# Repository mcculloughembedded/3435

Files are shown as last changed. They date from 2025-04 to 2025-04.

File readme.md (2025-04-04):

# The 3435
The *3435* is a 34 key split keyboard inspired by the [Clog V3](https://sammohr.dev/keyboards).
I have used it daily in a professional setting for more than a year.

Title Image

## Features
* 34 key split
* Low profile - only 18mm from top of keycap to desk (including feet)
* Kailh Choc V1 low profile switches
* MX standard key spacing
* Ortholinear
* Angled columns
* Vertical key staggering
* Pinky cluster
* Two key thumb cluster
* Wired USB-C to PC
* Integrated microcontroller (ATMega32u4)
* Fully enclosed case

# Table of Contents
* [Order PCBs](./instructions/order.md)
* [Program](./instructions/program.md)
* [Assemble](./instructions/build.md)
* [Bill of Materials](./instructions/bill-of-materials.md)

Secondary Image

# What's With the Name?
3435 is my favourite number.
It is the only known number where if one raises each digit to the power of itself, then adds the results, one gets back the original number.

That is <br/>
$$3^3 + 4^4 + 3^3 + 5^5 = 3435$$

See [Matt Parker's talk](https://www.youtube.com/watch?v=wt5cRQY8F30) for a more in depth discussion.

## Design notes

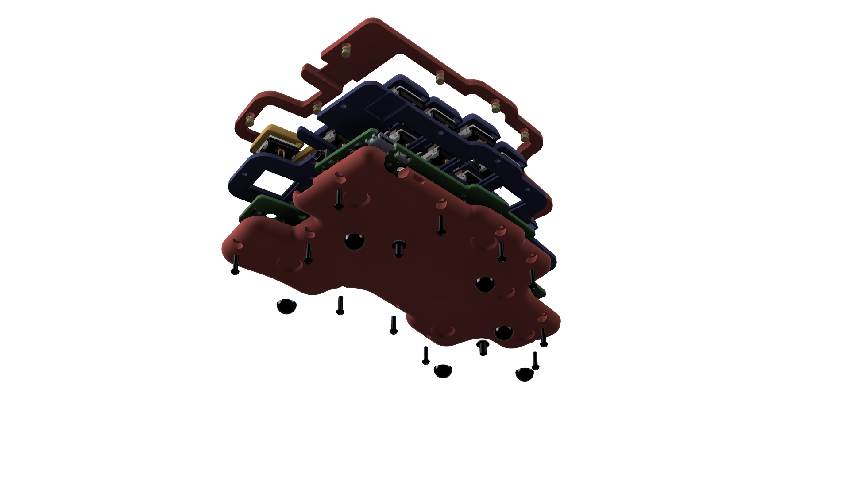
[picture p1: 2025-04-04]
collateral/renders/exploded-iso-bottom-left.png

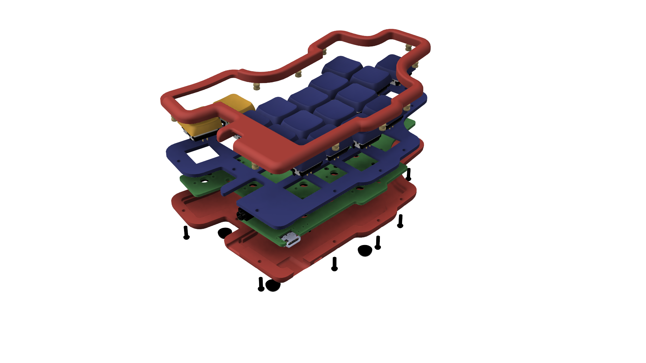
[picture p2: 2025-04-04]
collateral/renders/exploded-iso-right.png

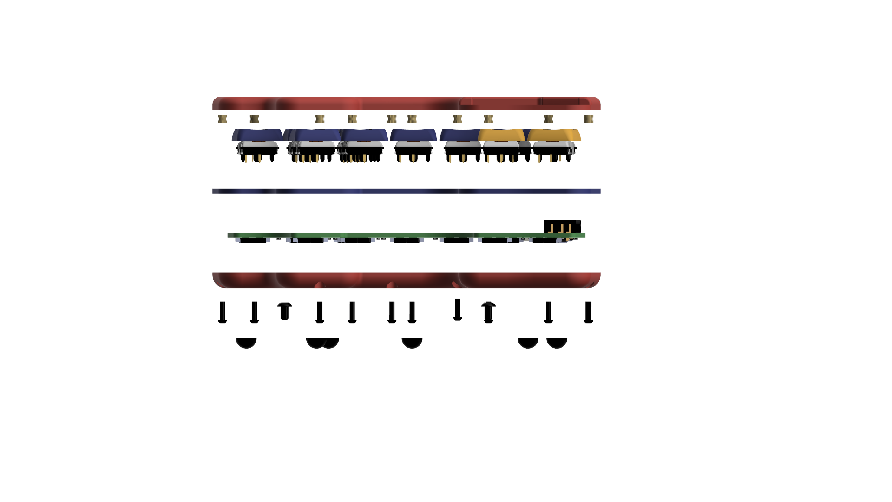
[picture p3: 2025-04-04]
collateral/renders/exploded-front.png

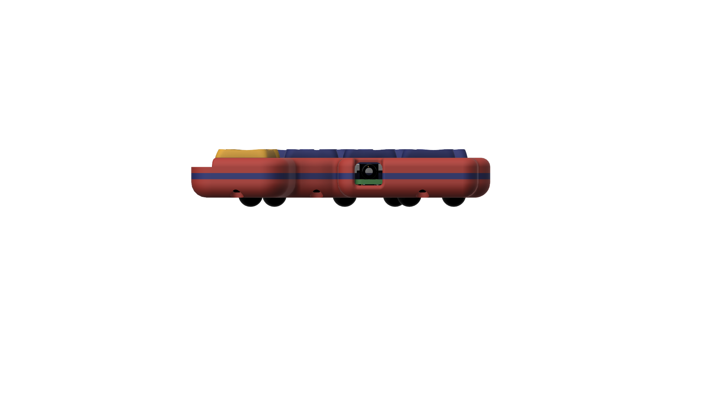
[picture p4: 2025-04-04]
collateral/renders/trrs-port.png

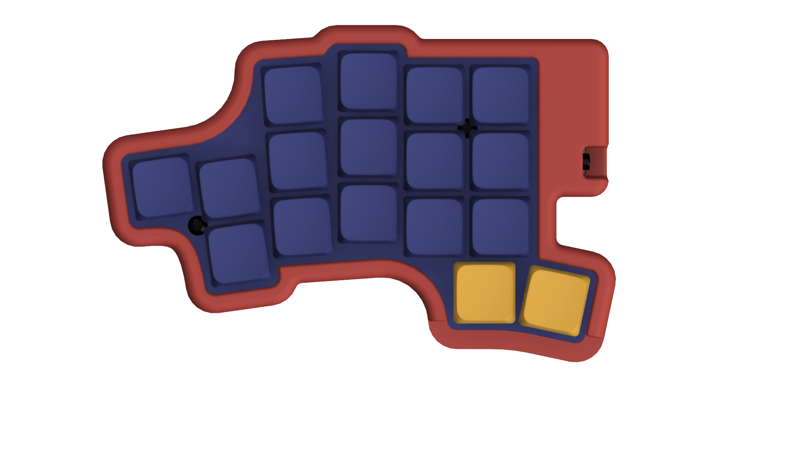
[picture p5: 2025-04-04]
collateral/renders/top.png

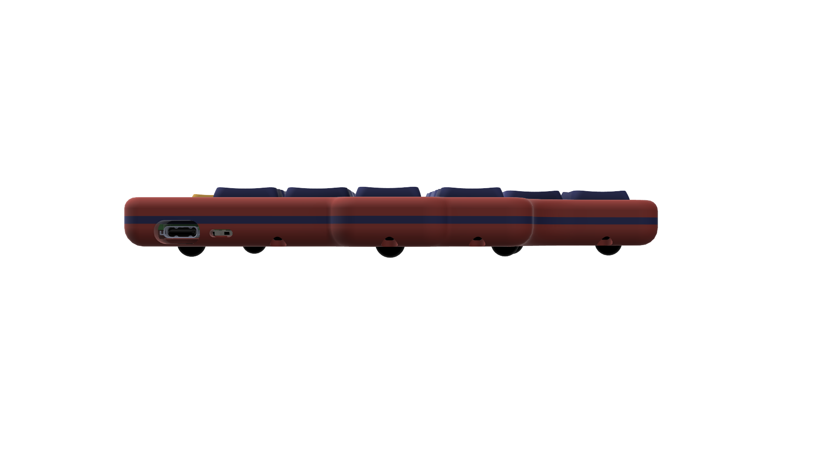
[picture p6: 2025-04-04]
collateral/renders/front.png

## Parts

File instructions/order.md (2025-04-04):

I use [JLCPCB](https://jlcpcb.com/) for all my PCBs.

# JLCPCB Datapacks
Each half of the keyboard is its own PCB order.
There are datapacks on the [Releases](https://github.com/mcculloughembedded/3435/releases) page with the required output files to order the PCBs from JLCPCB.
These datapacks include a bill of materials and a pick and place file excluding all top side components and the hot-swap sockets on the bottom side.

> :warning: **Disclaimer**<br>
The datapacks are unverified.
I did not have JLCPCB assemble everything for me.
Some components may be out of stock or no longer available.
In these cases you will have to select an alternative part from the JLC component library.
Make sure to double check everything before ordering!

If you would like to generate the output files yourself, there is a short discussion about doing so in the [Do It Yourself](#do-it-yourself) section.

# Order from JLCPCB
## Gerbers
If using a pre-generated datapack, simply upload `gerbers.zip` for each half of the keyboard.
The following options must be selected when uploading the gerber files.
Use your discretion for any other listed options.

| Option | Selection |
| --- | --- |
| Base Material | FR4 |
| Layers | 2 |
| PCB Thickness | 1.6mm |
| PCB Color | Any |
| Surface Finish | Lead Free HASL / ENIG[^1] |

## Assembly
This section is only relevant if JLCPCB will assemble the PCBs for you.

On the order page there is an option to have JLCPCB assemble the PCBs.
One thing to note here is that the USB-C connector is not on the same side as the rest of the components.
JLCPCB charges more to assemble both sides of the PCB.

The most economic way to do this is to have JLCPCB assemble the bottom side only.
Be warned though, soldering a USB-C connector is not a trivial task!

If using the datapacks, simply upload `bom.csv` and `pick-and-place.csv` when prompted and edit according to your needs.

JLCPCB has an online interface to visually check the placement of components.
Make sure of the orientation of the diodes, crystal oscillator and microcontroller.
I always edit the pick and place file locally and re-upload.
That way I am left with a correct pick and place file on my computer once all the corrections have been made.

Also make sure that JLCPCB stocks the parts in the bill of materials.
Again, they have an online interface to help with this.

# Do It Yourself

The requirements for a different PCB manufacturer will be similar but different to what is outlined here.

## PCB Output Files

At a minimum, PCB manufacturers require gerber and drill files to make the PCBs.

Consult the requirements of your chosen PCB manufacturer to know what they require.
For example, JLCPCB's website states that they require the following layers
* Top Copper
* Bottom Copper
* Top Solder Mask
* Bottom Solder Mask
* Top Silkscreen
* Bottom Silkscreen
* Board Outline

Each half of the keyboard is it's own [KiCad](https://www.kicad.org/) project.
Install KiCad and open each project using the *.kicad_pro* files in the `/pcbs/left` and `/pcbs/right` folders.

PCB manufactures often specify how to export gerber files correctly for different PCB software.
I used KiCad 7 and followed [these instructions](https://jlcpcb.com/help/article/how-to-generate-gerber-and-drill-files-in-kicad-7).

If you would like JLCPCB to assemble the PCBs for you, you must provide them with a bill of materials and a pick and place file.
JLCPCB has very specific requirements for these files.
KiCad does not export these files in the correct format for JLCPCB.
You have to edit them manually.
Consult the [JLCPCB documentation](https://jlcpcb.com/help/article/How-to-generate-the-BOM-and-Centroid-file-from-KiCAD) for more details.

[^1]: In short, ENIG is better, HASL is cheaper. I managed fine with HASL.

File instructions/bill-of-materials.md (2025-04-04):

> :warning: **Disclaimer**<br>
This BOM was written more than a year after the parts were ordered.
Some parts may no longer be available.
Part numbers may be incorrect.
I highly recommend that you double check everything before ordering.

# PCBs

| Part | (JLC) Part Number/Name | Quantity  | Notes/Footprint |
| --- | --- | --- | --- |
| Left Side PCB | 3435-left.kicad_pcb | 1 | |
| Right Side PCB | 3435-right.kicad_pcb | 1 | |
| 12pF Capacitor | | 4 | 0402 |
| 0.1uF Capacitor | | 10 | 0402 |
| 1uF Capacitor | | 2 | 0603 |
| 4.7uF Capacitor | | 2 | 0603 |
| Schottky Diode | B5819W SL | 2 | SOD-123 |
| Diode | 1N4148W | 34 | SOD-123 |
| Poly Fuse | SMD0805B050TF | 2 | 500mA/0805 |
| 22R Resistor | | 4 | 0402 |
| 5k1 Resistor | | 4 | 0402 |
| 10k Resistor | | 2 | 0402 |
| Slide Switch | PCM12SMTR | 2 | |
| Hot Swap Sockets | PG1350 | 34 | |
| 3.5mm TRRS Jack | PJ-320A | 2 | |
| USB-C Connector | USB4520-03-0-A | 2 | Mid Mount |
| Crystal Oscillator  | X322516MLB4SI | 2 | 16MHz/SMD3225-4P |
| Microcontroller | ATMega32U4 | 2 | VQFN-44 (7x7) |

# Mechanical

| Part | Part Number/Name  | Quantity  | Notes |
| --- | --- | --- | --- |
| Case Top Left | top.step | 1 | |
| Case Bottom Left | bottom.step | 1 | |
| Case Plate Left | plate.step | 1 | |
| Case Top Right | top.step | 1 | Mirrored |
| Case Bottom Right | bottom.step | 1 | Mirrored |
| Case Plate Right | plate.step | 1 | Mirrored |
| Threaded Inserts | M2x3x3.5mm | 22 | |
| Screws | M2x7 | 22 | |
| Rubber Ball Feet | 8mm diameter | 12 | Half dome adhesive bottom |

# Other

| Part | Part Number/Name  | Quantity  | Notes |
| --- | --- | --- | --- |
| Switches | Kailh Choc V1 | 34 | |
| Keycaps Standard | Choc V1 Keycap 1u | 28 | Concave |
| Keycaps Home Row | Choc V1 Keycap 1u | 2 | Bump on keycap  |
| Keycaps Thumb Cluster | Choc V1 Keycap 1u | 4 | Convex |
| USB-C to USB-A Cable | | 1 | |
| TRRS Cable | | 1 | |
| Right Angle TRRS Adapter | | 2 | Optional |

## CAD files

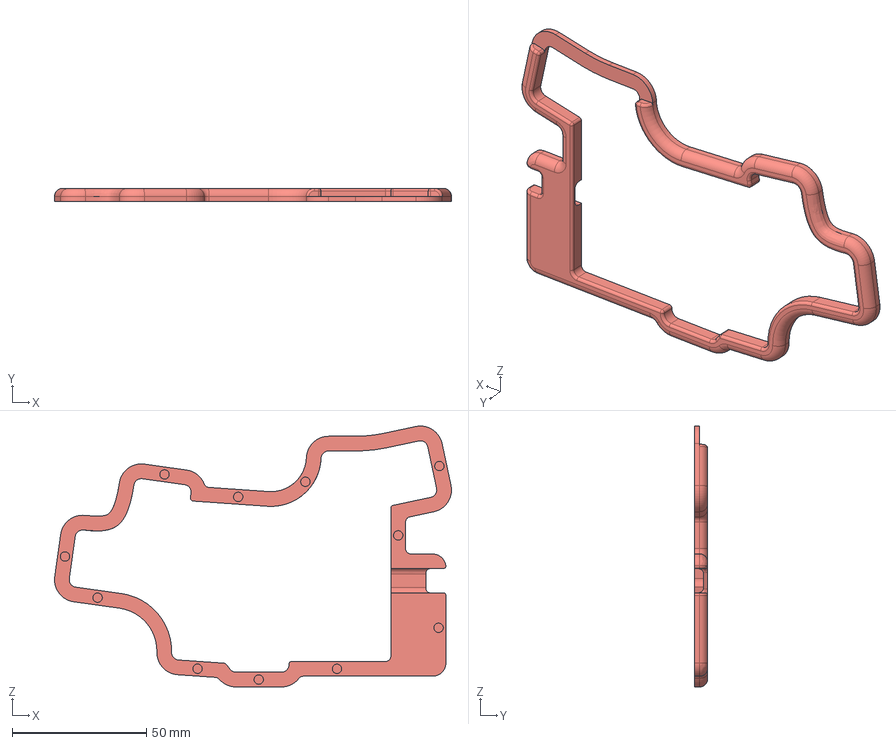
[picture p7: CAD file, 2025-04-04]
mechanical/top.step
148.1 x 5.00 x 97.3 mm

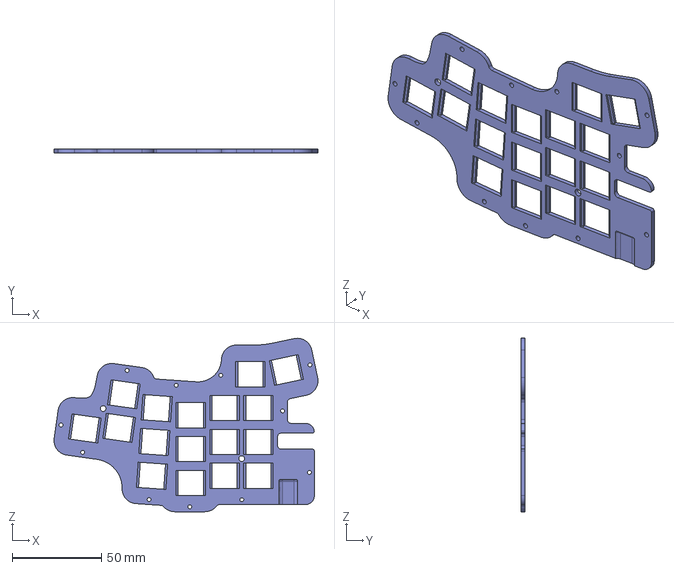
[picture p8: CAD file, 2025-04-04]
mechanical/plate.step
148.1 x 2.00 x 97.3 mm

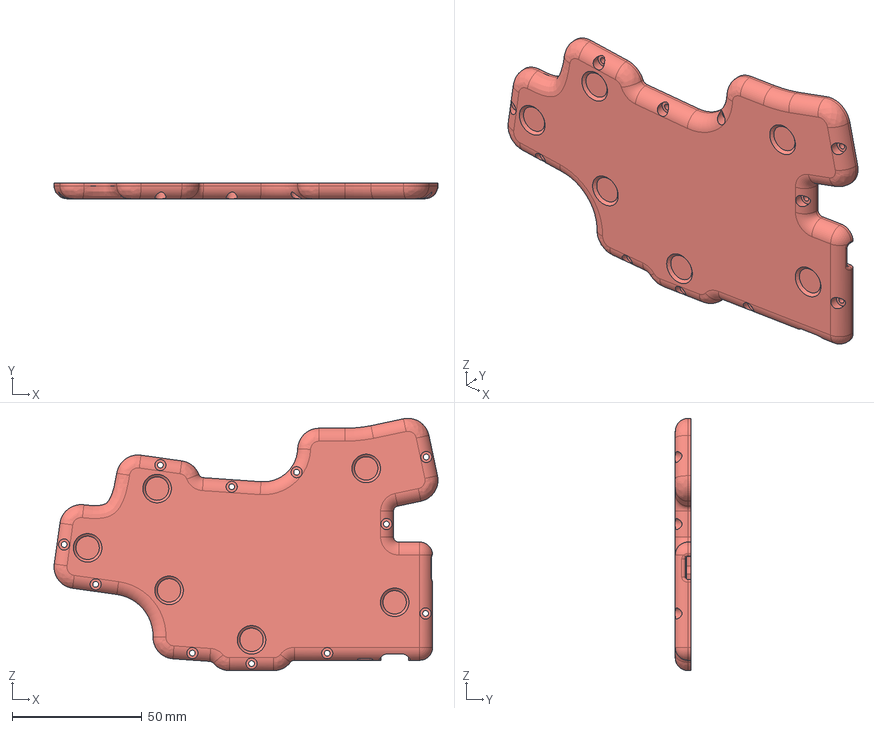
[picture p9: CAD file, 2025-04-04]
mechanical/bottom.step
148.1 x 6.00 x 97.3 mm

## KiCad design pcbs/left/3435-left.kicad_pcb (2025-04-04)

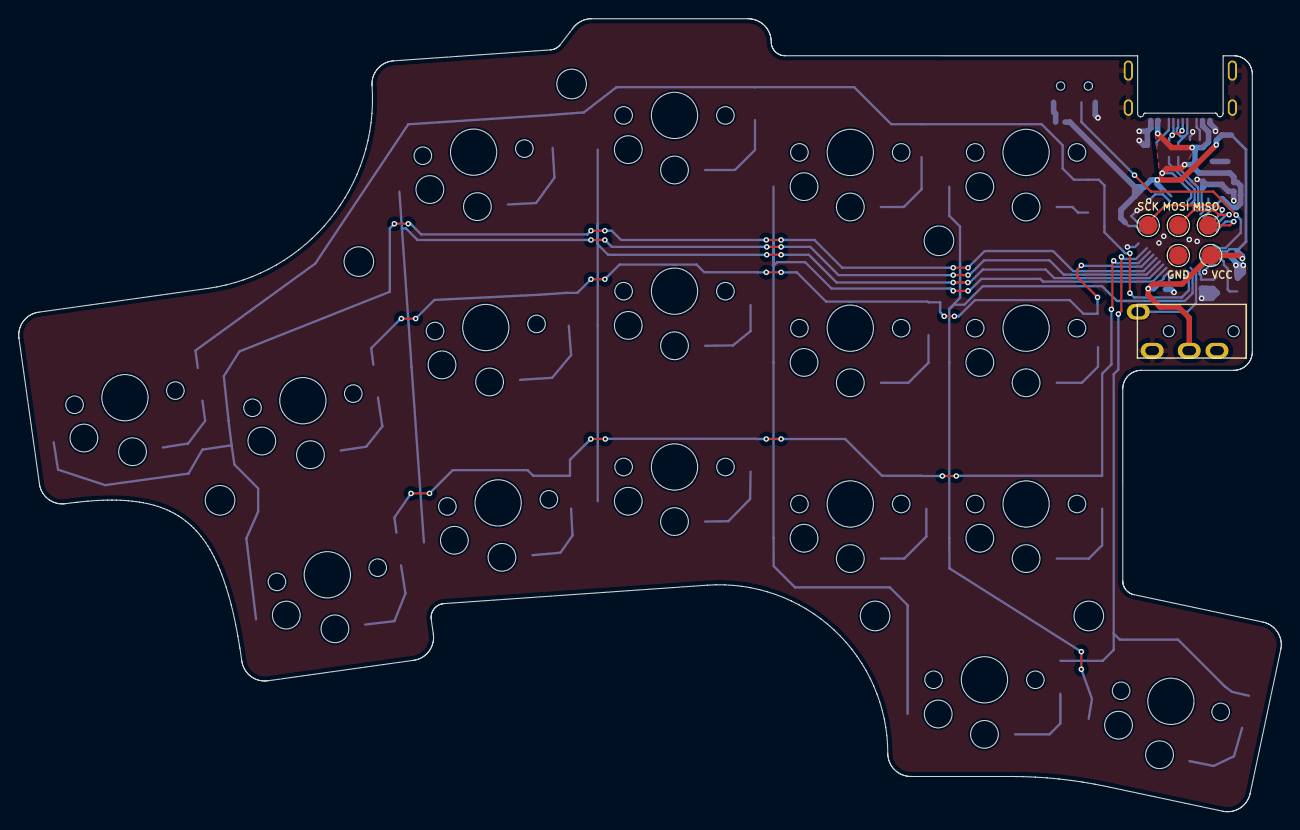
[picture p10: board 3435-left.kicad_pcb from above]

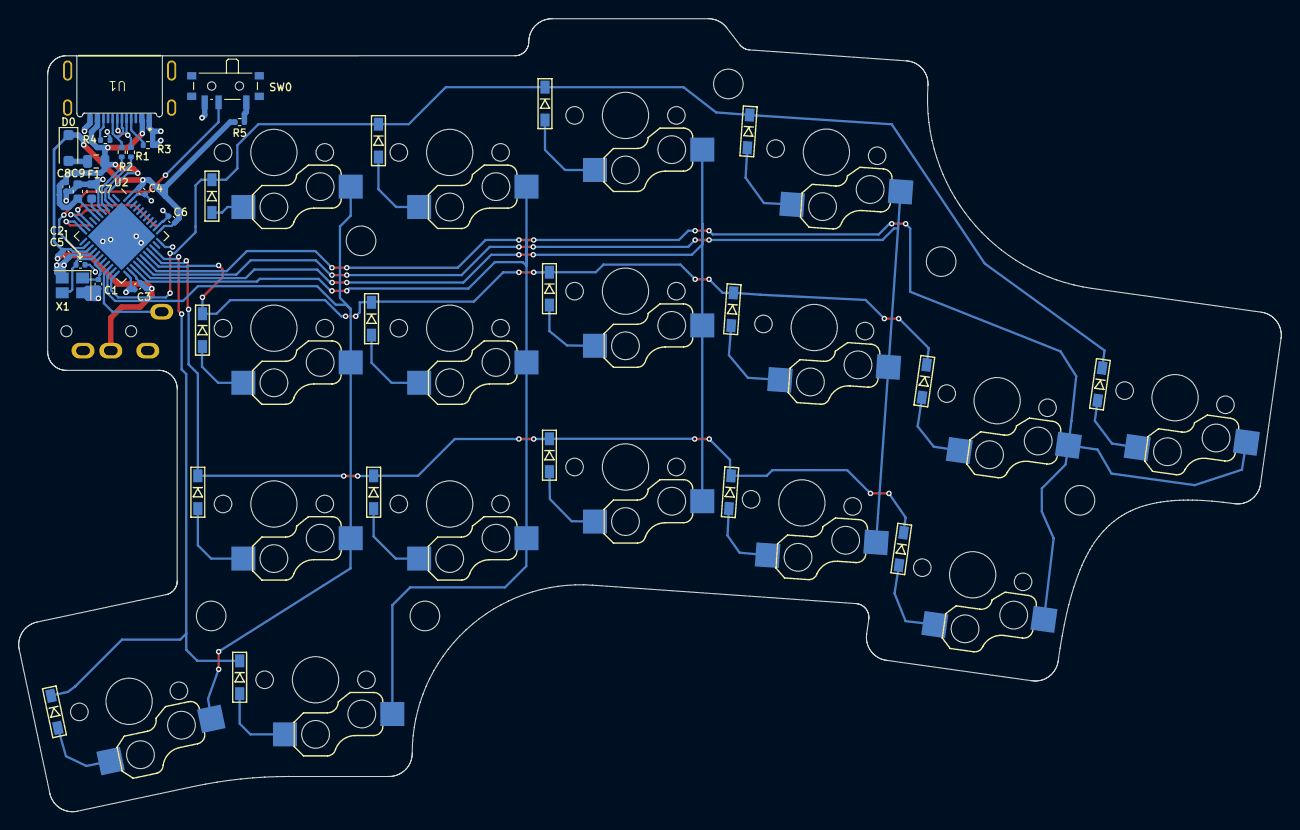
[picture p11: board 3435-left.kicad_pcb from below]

Board: 4 copper layers, 136.5 x 85.7 mm, 66 parts (37 on the bottom side), 45 nets.

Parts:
C1, C2: 12p; C_0402_1005Metric
C3, C4, C5, C6, C8: 0u1; C_0402_1005Metric
C7: 1u; C_0603_1608Metric
C9: 4u7; C_0603_1608Metric
D1, D2, D3, D4, D5, D6, D7, D8, D9, D10, D11, D12, D13, D14, D16, D17, D18: D; D3_SMD_v2
D15: D_Schottky; D_SOD-123F
F1: 500mA; Fuse_0805_2012Metric
H1, H2, H3, H4, H5, H6: MountingHole; MountingHole_3.2mm_M3
J1: MJ-4PP-9; MJ-4PP-9_1side
R1, R2: 22; R_0402_1005Metric
R3, R4: 5k1; R_0402_1005Metric
R5: 10k; R_0402_1005Metric
SW1, SW2, SW3, SW4, SW5, SW6, SW7, SW8, SW9, SW10, SW11, SW12, SW13, SW14, SW15, SW16, SW17: SW_PUSH; ChocV1_V2_Hotswap
SW18: SW_SPDT; SW_SPDT_PCM12
TP1, TP2, TP3, TP4, TP5: TestPoint; TestPoint_Pad_D2.0mm
U1: usb-mid-mount
U2: ATmega32U4-M; QFN-44-1EP_7x7mm_P0.5mm_EP5.2x5.2mm
X1: 16MHz; Crystal_SMD_SeikoEpson_FA238-4Pin_3.2x2.5mm

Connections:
/COL1: SW15.1, SW16.1, SW17.1, U2.28 (PB4)
/COL2: SW12.1, SW13.1, SW14.1, U2.27 (PD7)
/COL3: SW9.1, SW10.1, SW11.1, U2.26 (PD6)
/COL4: SW5.1, SW6.1, SW7.1, SW8.1, U2.25 (PD4)
/COL5: SW1.1, SW2.1, SW3.1, SW4.1, U2.21 (PD3)
/D+: R2.2, U2.4 (D+)
/D-: R1.1, U2.3 (D-)
/MISO: TP1.1, U2.11 (PB3)
/MOSI: TP4.1, U2.10 (PB2)
/RAW: D15.2 (A), F1.2
/RESET: SW18.2 (B), U2.13 (~RESET)
/ROW0: D1.1 (K), D5.1 (K), D9.1 (K), D12.1 (K), D16.1 (K), U2.22 (PD5)
/ROW1: D2.1 (K), D6.1 (K), D10.1 (K), D13.1 (K), D17.1 (K), U2.29 (PB5)
/ROW2: D3.1 (K), D7.1 (K), D11.1 (K), D14.1 (K), D18.1 (K), U2.30 (PB6)
/ROW3: D4.1 (K), D8.1 (K), U2.31 (PC6)
/SCK: TP2.1, U2.9 (PB1)
/serial: J1.A, U2.20 (PD2)
GND: C1.2, C2.2, C3.2, C4.2, C5.2, C6.2, C7.2, C8.2, C9.2, J1.D, R3.2, R4.1, SW18.3 (C), TP5.1, U1.A1_B12 (GND), U1.B1_A12 (GND), U1.S1 (SHIELD), U1.S2 (SHIELD), U1.S3 (SHIELD), U1.S4 (SHIELD), U2.5 (UGND), U2.15 (GND), U2.23 (GND), U2.33 (~HWB/PE2), U2.35 (GND), U2.43 (GND), U2.45 (GND), X1.2, X1.4
unnamed: D1.2 (A), SW1.2
unnamed: D2.2 (A), SW2.2
unnamed: D3.2 (A), SW3.2
unnamed: D4.2 (A), SW4.2
unnamed: D5.2 (A), SW5.2
unnamed: D6.2 (A), SW6.2
unnamed: D7.2 (A), SW7.2
unnamed: D8.2 (A), SW8.2
unnamed: D9.2 (A), SW9.2
unnamed: D10.2 (A), SW10.2
unnamed: D11.2 (A), SW11.2
unnamed: D12.2 (A), SW12.2
unnamed: D13.2 (A), SW13.2
unnamed: D14.2 (A), SW14.2
unnamed: D16.2 (A), SW15.2
unnamed: D17.2 (A), SW16.2
unnamed: D18.2 (A), SW17.2
unnamed: R1.2, U1.A7 (D-), U1.B7 (D-)
unnamed: R2.1, U1.A6 (D+), U1.B6 (D+)
unnamed: R5.1, SW18.1 (A)
unnamed: R3.1, U1.A5 (CC)
unnamed: R4.2, U1.B5 (VCONN)
unnamed: C7.1, U2.6 (UCAP)
unnamed: C1.1, U2.17 (XTAL1), X1.1
unnamed: C2.1, U2.16 (XTAL2), X1.3
VBUS: C8.1, C9.1, F1.1, U1.A4_B9 (VBUS), U1.B4_A9 (VBUS), U2.2 (UVCC), U2.7 (VBUS)
VCC: C3.1, C4.1, C5.1, C6.1, D15.1 (K), J1.C, R5.2, TP3.1, U2.14 (VCC), U2.24 (AVCC), U2.34 (VCC), U2.44 (AVCC)

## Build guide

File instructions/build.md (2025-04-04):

# PCB Assembly

Solder all components onto both the left and right hand side PCBs.
The microcontroller and USB-C connector are difficult to solder with a soldering iron.
The crystal oscillator must be soldered with a hot air station or oven.
The rest of the components can be soldered with a soldering iron, although there are a few 0402 components which can be a challenge.

Make sure to solder the diodes, crystal oscillator and microcontroller in the correct orientation!

PCB manufacturing outlets often provide an assembly service for an extra fee.
See [here](./order.md#Assembly).

# Mechanical Assembly

Before assembling the keyboard, make sure the [correct bootloader](./program.md#Bootloader) has been loaded!

The case is designed to be 3D printed on an FDM printer without supports.
I printed mine on my stock Creality Ender 3 V2.

1. 3D print `top.step`, `bottom.step` and `plate.step` from the `/mechanical` folder.
2. Push fit the threaded inserts into the holes on the bottom of *top.step*.
   This is best done by heating up the threaded inserts with a soldering iron before pushing them into position.
3. Clip the switches into their places on the top side of *plate.step*.
   There is only one way in which they will clip into place.
   The bottom side of *plate.step* has ridges onto which the switches clip.
4. With the PCB on the bottom side of *plate.step*, push the switches into their hot-swap sockets.
5. Sandwich *plate.step* in between *bottom.step* and *top.step*.
6. Screw in the screws from the bottom of the keyboard into the threaded inserts.
7. Stick on a rubber foot in each of the circular dents on the bottom of *bottom.step*.
8. Mirror the files in step 1, and repeat steps 2 to 7 for the right half of the keyboard.

## Threaded Insert Assembly
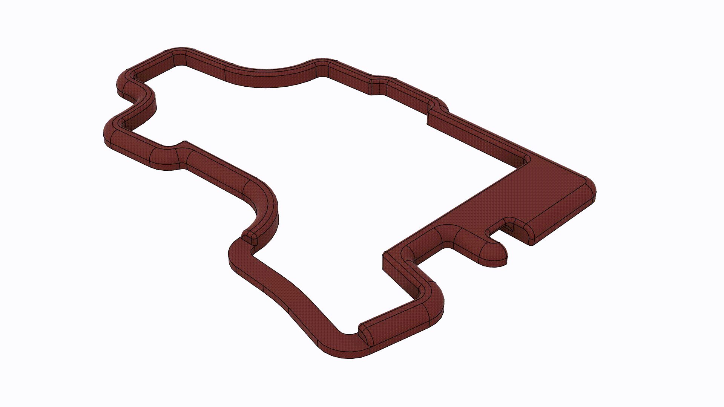
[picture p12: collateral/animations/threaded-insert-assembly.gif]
Threaded Inserts

## Final Assembly
Final Assembly

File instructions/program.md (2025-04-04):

The 3435 uses [QMK](https://qmk.fm/).
You are welcome to use whatever firmware is compatible with an ATMega32u4 microcontroller.

The firmware on the microcontroller is composed of two sections.
1. The Bootloader
2. QMK

The bootloader runs when the microcontroller is powered on and handles the startup procedure.
Once the startup is complete, the bootloader starts the QMK part of the code.
The bootloader also provides a way of reprogramming the QMK part of the firmware via USB.
This is how the firmware and keymap are updated.

The QMK part of the firmware is what makes the keyboard a keyboard.
It checks for switch presses and reports them to the computer through USB.

# Bootloader
By default, the 3435 is configured to use the default Microchip bootloader.
This comes pre-programmed on the device in most cases.

If you purchased your ATMega32u4 from an Arduino outlet, it may have the *Caterina* bootloader on it.
In this case, you can modify `info.json` in the `/qmk` folder or you can flash the default Microchip bootloader over ISP.

The QMK documentation describes the [process of flashing a new bootloader](https://docs.qmk.fm/isp_flashing_guide) very well.

# QMK
The QMK documentation is extremely thorough.
I highly recommend going through the [tutorial](https://docs.qmk.fm/newbs) from start to finish once before continuing.

To get the 3435 going
1. Use the QMK CLI tool to create a new keyboard called '3435' using the [new-keyboard](https://docs.qmk.fm/cli_commands#qmk-new-keyboard) command.
   The `--help` switch is useful here!
2. Copy over the files from the `/qmk` folder into the newly created `/keyboard/3435` directory in the QMK root.
3. Build and flash the firmware by following the QMK documentation.

To program the 3435 via USB, flip the switch next to the USB-C connector, then power on the board over USB.
Each side must be programmed separately.
Remember to flip the switch back to boot normally once you are done with the programming.

From here on you can edit `keymap.c`, `rules.mk` and `config.h` to edit the keymap.
The QMK documentation is your friend!

# Via
[Via](https://www.caniusevia.com/) is a graphical interface for configuring QMK based keyboards.
Unfortunately, I choose not to use it and so I have not made a Via configuration for the 3435.
If the 3435 ever becomes popular enough to be added to the QMK master branch, I may consider making it Via compatible.

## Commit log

2025-04-03 feat(pcbs): add right side
    [3435-right.kicad_pcb, 3435-right.kicad_sch]
2025-04-03 chore(.gitignore): ignore kicad generated files
2025-04-03 feat(pcbs): add left side
    [3435-left.kicad_pcb, 3435-left.kicad_sch, board-outline-clean.dxf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]
2025-04-03 chore(*): move mechanical files into separate folder
    [board-outline-clean.dxf, outline.dxf]
2025-04-03 feat(instructions): add
    Getting going. Lots to add...
    [board-outline-clean.dxf, bottom.step, outline.dxf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]
2025-04-03 fix(build.md): assembly gif
2025-04-03 feat(build.md): add threaded insert assembly gif
2025-04-03 fix(build.md): use the correct gif for threaded insert assembly
2025-04-03 chore(collateral): add threaded-insert-assembly gif
2025-04-04 docs(bill-of-materials): add
2025-04-04 docs(bill-of-materials): add PCB components
2025-04-04 docs(bill-of-materials): add disclaimer
2025-04-04 fix(*.kicad_pcb): add solder mask to USB-C connector
    Problem:
    There was no solder mask on the USB-C connector, so all the pads were
    covered.
    Solution:
    Add the solder mask to the USB-C connectors.
    Note that this was done on each board, as these files no longer have
    shared footprints.
    [3435-left.kicad_pcb, 3435-right.kicad_pcb]
